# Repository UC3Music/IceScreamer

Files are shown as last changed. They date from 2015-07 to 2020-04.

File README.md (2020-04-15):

# IceScreamer
UC3Music's version of the well known green guitar pedal: Ibanez's Tube Screamer.

[Este mismo artículo en español](https://github.com/UC3Music/IceScreamer/blob/master/LEEME.md)

This project has a very similar electronics to Ibanez TS-808 TubeScreamer. Moreover this board let you choose among several modifications of the original design, and implement it easily. The most important modification is the ability to build a true bypass or buffered bypass pedal. Also there will be plenty of room for the most usual mods out there:

- Easier to provide "more gain"
- Easy to replace Op-Amp
- Easy to swap diodes (different distortion sounds)
- Easy to swap between flavors TS5, TS10 and TS808

## Choose from true bypass or pseudo true bypass.
From a manufacture perspective, true bypass isn't a convenient design, since it requires a big and expensive three pole, dual trow switch. And because it's bulkiness and complexity it needs to be soldered by hand. Buffered bypass is the way several manufacturers (Boss, Ibanez) reduced fabrication cost. However you need to solder 30 more components to get buffered bypass working, this circuit is more interesting in very automated manufacturing lines.

Among other benefits, true bypass means that, when your pedal is off, signal passes completely unaltered trough the pedal, as a wire tying together the input and output jack. Your tone will be perfect, however this bypass method has two disadvantages:

- A loud "click" sound can be made at the switch and then amplified by your guitar amp.
- If you are using long cable runs (i.e. 6m from guitar to pedalboard, then 6m from pedalboard to amp) you will have treble loss because guitar's high impedance output signal is affected a lot by cable capacitance.

Pseudo true bypass (buffered bypass) means that, when pedal is off, signal passes trough one or more buffers. A buffer is a kind of amplifier with gain of 1. Neither amplifies or attenuates signal. Buffers are designed to not alter the sound, but according to this [YouTube Video](https://www.youtube.com/watch?v=-oxBlWmeGE0), using more than five buffered pedals, bypass can trim down some bass frequencies and a little high frequencies. The benefits from buffered bypass are:

- No "click" silent switching.
- After the buffered pedal no matter how many cable meters you put, you no longer have treble loss. Pedal's output has low impedance, so cable capacitance reduce highs less.

TL;DR: using a lot of buffered bypass pedals is not good because you can end with a high-passed guitar sound. Using only true bypass pedals is not good if you handle long cable runs. Putting some buffered bypass pedal provide the best of the two worlds solution.

If you choose to build your IceScreamer with true bypass, short only "Short for TruBy" jumper located under "MILK" connector. If you choose to build your IceScreamer with pseudo true bypass, short only the two "Short both for Pseudo" jumpers, located in between input and output jacks.
Do it with a little of solder.

## Let's begin soldering
Components appears in the order it is meant to be soldered, from little to bigger size. If you need advice on how to solder, check this videos.
- [Tutorial SMT4Dummies by David Antón](https://www.youtube.com/watch?v=AYtE7eyIIUI&t=5s) Hand soldering wet technique.
- [Tutorial by informaticaIT](https://www.youtube.com/watch?v=BA7luKtNBzU) SMT with hot air gun.
- [Tutorial by ItsInOurKernel](https://www.youtube.com/watch?v=PU7wLcuqc-I) Hand soldering SMT.
- [Tutorial by EEVBlog](https://youtu.be/b9FC9fAlfQE?t=405) Hand soldering SMT.
- [Tutorial SMT4Dummies de JorFru (Spanish)](https://www.youtube.com/watch?v=6ee5rFPXXJo) Hand soldering dry technique.

## Where to place components?
Check the interactive component placement [viewer](http://music.uc3m.es/IceScreamer/BOM)

### Placing resistors
All resistors are SMD 2012(metric) or SMD 0805(imperial) size. You must have in mind all resistors measure 2,00mm x 1,25mm.
Resistors are thick film metal resistors.
10R stands for 10 ohms, 10K stands for 10000 ohms.

- R1, R2, R5, R6, R10, R15 and R17: 10K
- R3, R9, R11, R13: 1K
- R4, R14: 470K
- R7: 47K
- R8: 4,7K
- R12: 220R
- R16: 100R
- R18: SOLDER ONLY FOR TRUE BYPASS. Current limiting resistor for LED indicator. For using the ring LED provided in the BOM, use 470R. For single red LED on true bypass, use 680R.
- R19: 10K (only in case you are using a linear 100K potentiometer on volume and you want to provide a logarithmic feel)

If you are assembling true bypass, stop here. The following are the resistors for pseudo true bypass.

- R20 and R21: 470K
- R22, R26 and R32: 1M
- R23, R24, R30, R31, R34: 56K
- R25: 22K
- R27: 22R
- R28 and R29: 47K
- R33: 0R
- R35: current limiting resistor for pseudo true bypass LED indicator. 36K for standard red LED. Need calculation for other color.
- R36: 100R

### Capacitors
All capacitors are SMD 2012(metric), 0805(imperial) sized. To clarify: this component measures 2,0mm x 1,25mm.

Ceramic capsin case it is not specified.

- C3, C4, C12, C14, C15, C16, C17 and C18: 100nF
- C5: 22nF.
- C6 y C11: 1uF. Footprints are wrong here, you should solder polyester caps here, for improving the sound.
- C7: 47pF, Trough hole mounted
- C8: 47nF, Trough hole mounted
- C9: 220nF.
- C10: 220nF, Trough hole mounted
- C13: 10uF.

If you are assembling true bypass version, stop here. If you are assembling pseudo true bypass, continue soldering the following caps.
- C20: 100nF
- C21 and C27: 47nF
- C22, C25 and C26: 1nF
- C23 and C24: 100pF

### Diodes
Apart of D1 and D4 which are THD, others are 2012 metric (0805 imperial), however you can solder MicroMELF packages.

- D1: 1N4001, or any other general purpose 1A diode.
- D2 y D3: 1N4148
- D4: LED status (on/off) indicator

If you are assembling true bypass version, stop here. If you are assembling pseudo true bypass, continue soldering the following diodes.

- D20, D21 y D22: 1N4148
- D23: Zener 4.7V

### Transistors
Transistors are placed as seen on paintings on the board. If you are using other than the BC547, wich is suggested, pinouts will differ. Check this picture.
<p align="center">
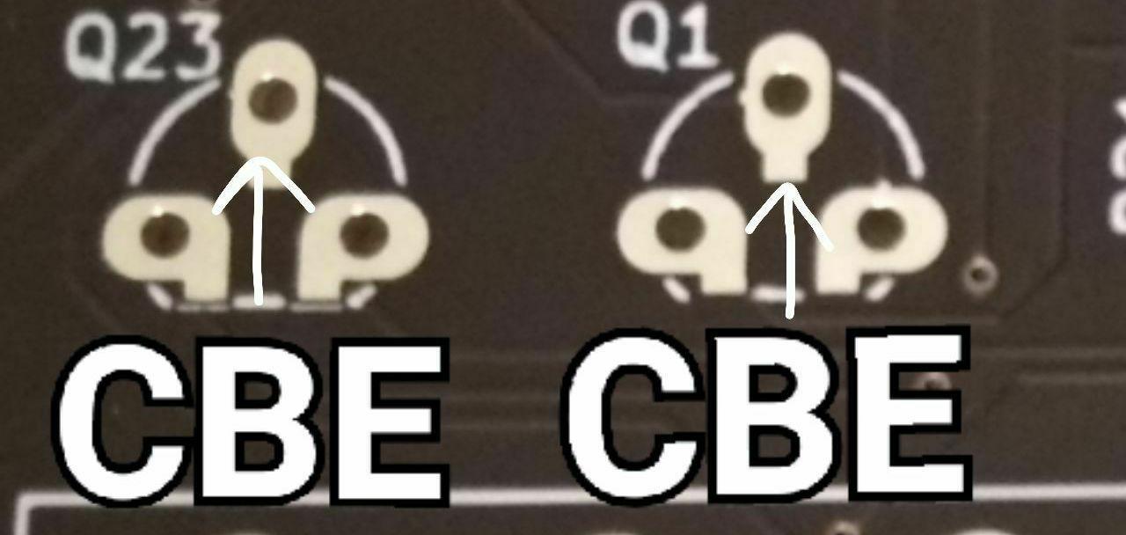
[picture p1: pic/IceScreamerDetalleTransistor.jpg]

</p>

- Q1, Q2: [BC547](https://www.tme.eu/es/details/bc547-cdi/transistores-npn-tht/cdil/bc547/). You can use any NPN transistor, but check pinouts.If you are assembling true bypass version, stop here. If you are assembling pseudo true bypass, continue soldering these transistors.

If you are assembling true bypass version, stop here. If you are assembling pseudo true bypass, continue soldering these transistors.

- Q20, Q21 y Q22: [BC547](https://www.tme.eu/es/details/bc547-cdi/transistores-npn-tht/cdil/bc547/). You can use any NPN transistor, but check pinouts.

- Q23 y Q24: [MMBF4392L](https://www.tme.eu/es/details/mmbf4392lt1g/transistores-con-canal-n-smd/on-semiconductor/). This is a JFET transistor. It's easy to find in CBE configuration.

### Integrated circuit
We recommend to install a socket for easy IC swapping.
U1: JRC4558. We use [RC4558](https://www.tme.eu/es/details/rc4558p/amplificadores-operativos-tht/texas-instruments/), but you can use any "dual OP-Amp", I.E.: NE5532,TL082, etc.

### Potentiometers
- ICE (Drive): 470K lineal
- CREAM (Tone): 20K lineal
- MILK (Level): 100K logarithmic or lineal installing 10K on R19. Learn more about Lin to Log conversion [here](https://learnabout-electronics.org/Resistors/resistors_09a.php)

### Switches
For True Bypass, solder a [3PDT](https://es.aliexpress.com/item/32530834644.html?spm=a2g0s.9042311.0.0.1ec663c0FUsGGv) (also called TPDT) switch in "SW_TruBy" mark.
If you are assembling pseudo true bypass, solder a momentary button [SPST](https://es.aliexpress.com/item/32918205335.html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,searchweb201602_,searchweb201603_) in the "SW_Pseudo" mark. Before soldering, put the cables trough the holes to secure it and avoid damage in case of strong pull.

### Battery cell
Battery cell Connect your battery lead to "9V Batt" mark, mind its polarity. Before soldering, put the cables through the holes to secure it and avoid damage in case of strong pull. Check picture.
<p align="center">
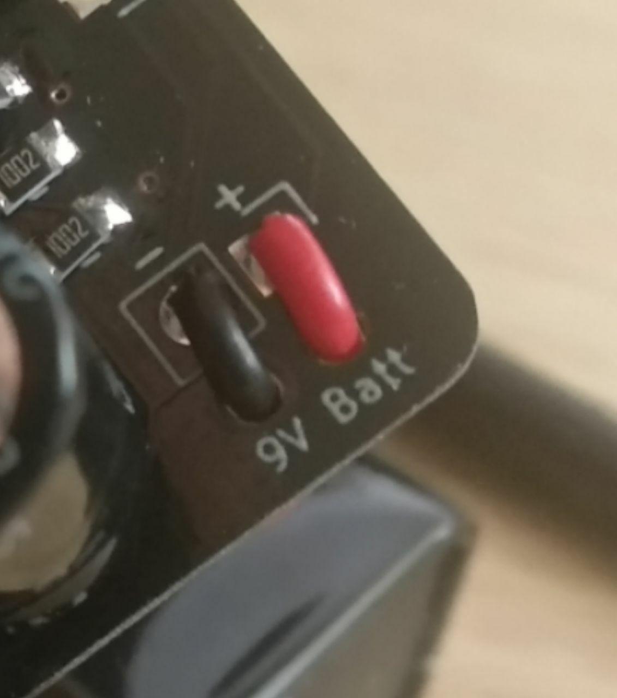
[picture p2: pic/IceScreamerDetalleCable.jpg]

</p>

### Big components last assembled

- C1 y C2: electrolytic caps, 220-470uF, at least 15V. Better use low-ESR. Lead spacing is 2.54mm.

### Jacks
Input and output are using Amphenol [ACJS-IH](https://www.tme.eu/en/details/acjs-ih/jack-connectors/amphenol/) connectors.
But seems that Neutrik [NMJ6HFD2](https://www.tme.eu/es/details/ntr-nmj6hfd2/conectores-jack/neutrik/nmj6hfd2/) are compatible too, not tested yet.

## Main mods
### More gain
If you want more distortion, lower that 4.7K R8 to get more gain when the drive control is maxed out. If you don't also want to change the bass/treble response, you will need to change the capacitor C8 as well. If you half the resistor, double the capacitor to keep the same overall frequency response. In example, R8 from 4.7K to 2.2K (you can use two 4.7K in parallel), C8 cap from 47nF to 100nF (you can use two 47nF caps in parallel)

It's also possible to increase gain potentiometer's value from 470K to 1M. 

### More bass
Increase C8 value. I.E.: C8 from 47nF to 100nF. Or 200nF if you already done the "more gain" mod.

### Swapping distortion flavour.
The stock units use a pair of silicon signal diodes, which are a 1N4148. If you change one of these diodes, chances are that the resulting pair will not clip at the same voltage for positive and negative signals, giving you asymmetrical clipping, and the resulting even order distortion. If you pick something close, like maybe a silicon power diode like the 1N400x series for the second diode, the resulting second harmonic will be very subtle, not audible as an octave effect at all, just a "sweeter" or more liquid tone.

You can try a number of things like putting one germanium (1N34A from Radio Shack works) diode in series with one of the silicons to add a bit more threshold voltage to one side. A more radical treatment would be the replacement of one of the silicons with three germaniums; even more radical would replace one of the silicons with TWO silicons. These last will start to make an octave effect just barely audible at some notes on the guitar neck.

I've even heard of using LED's in there for the clipping diodes. Go wild here.

## Otros mods:
On [this site](https://www.electrosmash.com/tube-screamer-analysis) I read that [this transistors](https://www.tme.eu/es/details/2sc1815-cen/transistores-npn-tht/central-semiconductor-corp/2sc1815/) are more silent than the suggested BC547. But check pin out when swapping transistors! However, on first prototypes, there's no noise issues with suggested parts. Through Q1 and Q2 is sound passing by, meanwhile there's no signal passing through Q20, Q21 nor Q22. If you are interesting in transistor swapping, consider only doing it on Q1 and Q2.

## References
This project and documentation were inspired in the following posts:
- http://www.geofex.com/Article_Folders/TStech/tsxfram.htm
- https://www.electrosmash.com/tube-screamer-analysis
- https://www.muzique.com/tech/scream.htm

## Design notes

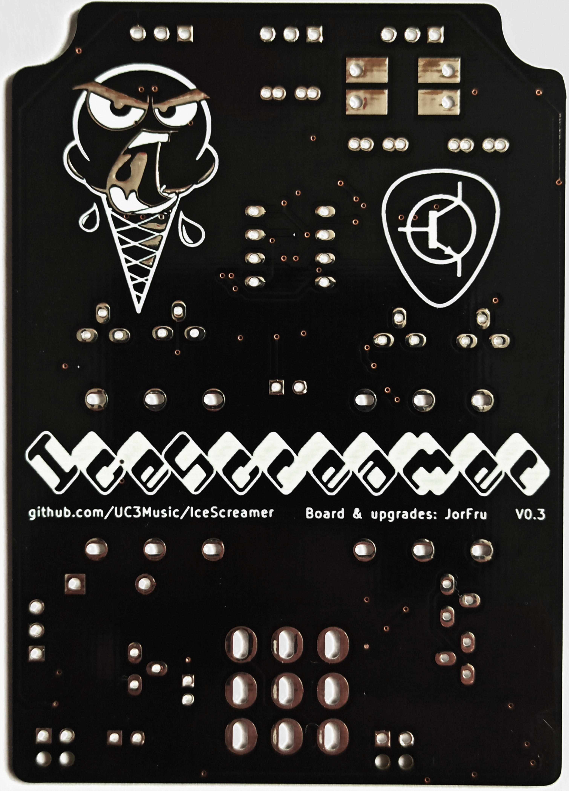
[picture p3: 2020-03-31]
pic/IceScreamerBottom.jpg

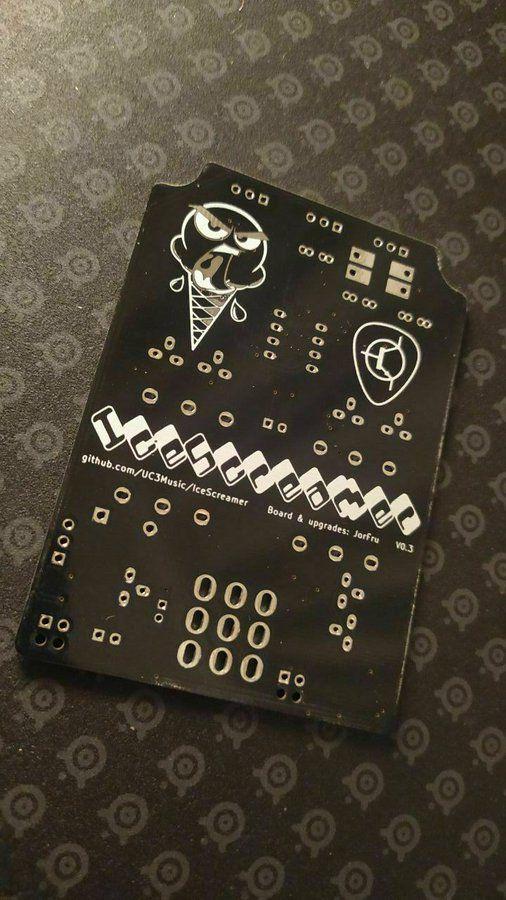
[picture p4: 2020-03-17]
pic/IceScreamerPic0.jpg

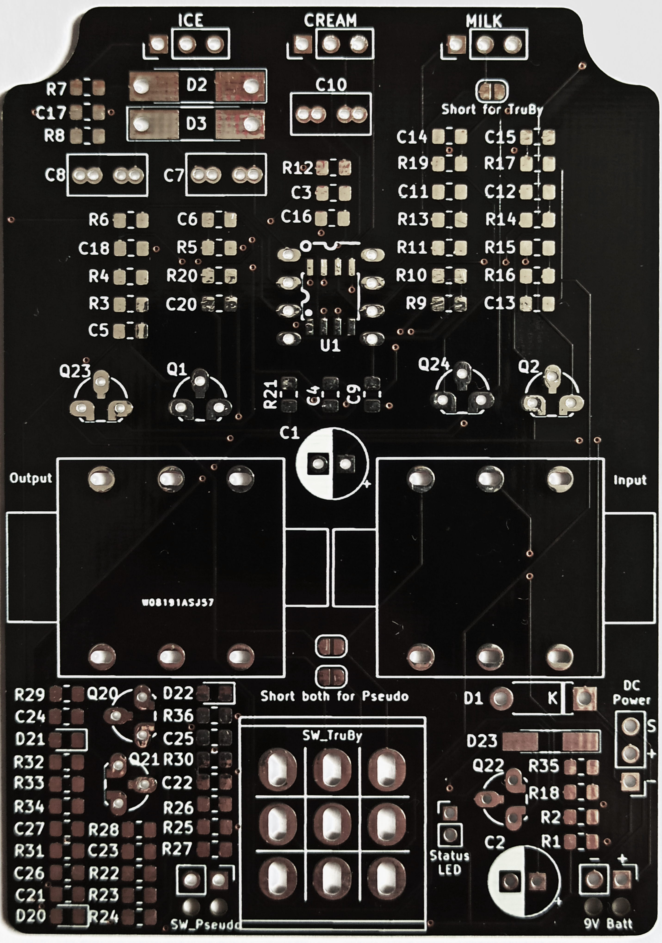
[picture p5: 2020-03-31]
pic/IceScreamerTop.jpg

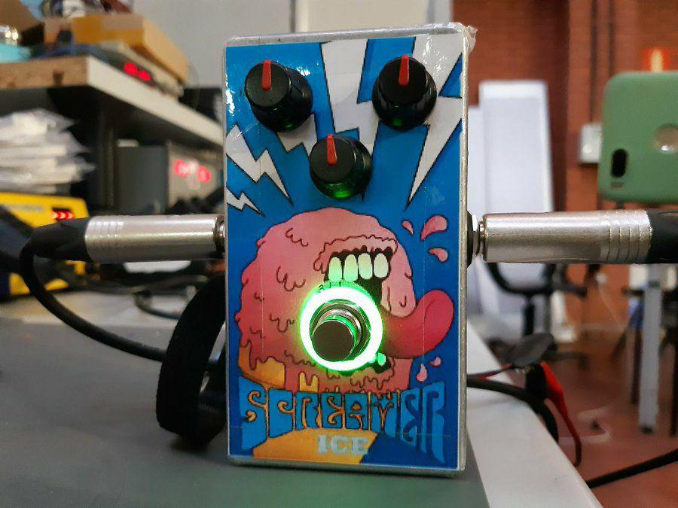
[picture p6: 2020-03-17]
pic/IceScreamerPic3.jpg

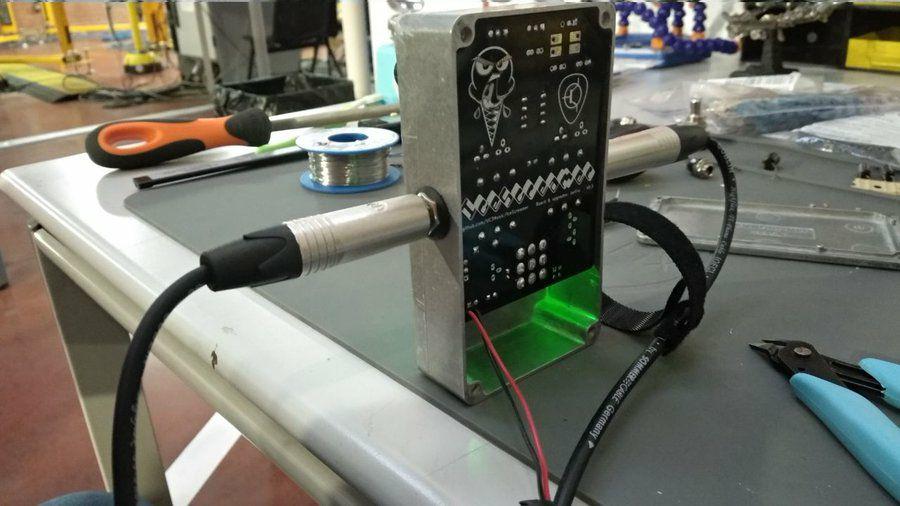
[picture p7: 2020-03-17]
pic/IceScreamerPic2.jpg

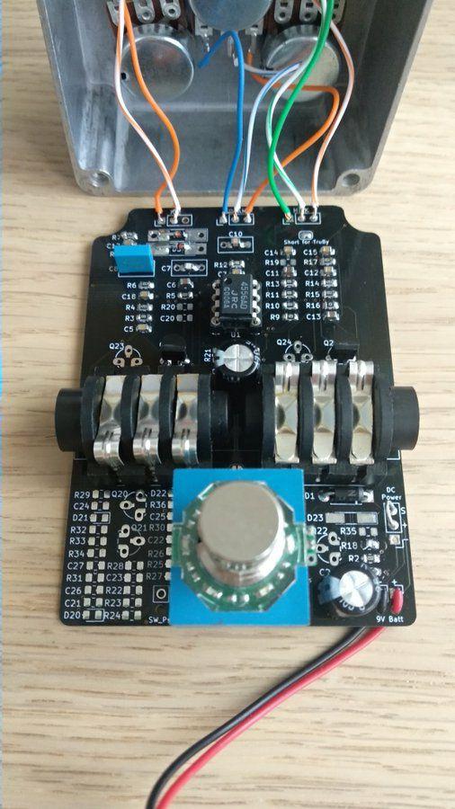
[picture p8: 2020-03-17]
pic/IceScreamerPic1.jpg

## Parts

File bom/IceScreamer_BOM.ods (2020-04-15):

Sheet: TrueByPass
Qty | Item | Manufacturer | Part Nº | Link | Supplier | Notes | Unit cost | Cost
1 | IC | TI | RC4558 | http://www.tme.eu/en/details/rc4558p/tht-operational-amplifiers/texas-instruments/ | TME | Actual part, ubiquitous | 0,15 | 0,15
1 | DIP socket |  | 1-2199298-2 | https://www.tme.eu/en/details/1-2199298-2/standard-dip-sockets/te-connectivity/ | TME |  | 0,21 | 0,21
1 | Enclosure | Hammond | 1550B | http://www.tme.eu/es/details/hm-1550b/carcasas-universales/hammond/1550b/ | TME |  | 5,75 | 5,75
2 | Jacks | Amphenol | acjx-ih | http://www.tme.eu/en/details/acjs-ih/jack-connectors/amphenol/ | TME |  | 0,83 | 1,66
0 | Alt Jack | Neutrik | NMJ6HCD2 |  |  |  | 0,00 | 0,00
1 | PCB | PCBWay, 123PCB, SeeedStudio, etc |  | https://www.pcbway.com/ | PCBWay |  | 1,40 | 1,40
1 | Pot TONE | SR PASSIVES | R16148-1A-2-B22K | http://www.tme.eu/en/details/r16148-1a-2-b22k/carbon-single-turn-axial-potentiometers/sr-passives/ | TME |  | 0,31 | 0,31
1 | Pot LEVEL | SR PASSIVES | R16148-1A-2-A100K | http://www.tme.eu/en/details/r16148-1a-2-a100k/carbon-single-turn-axial-potentiometers/sr-passives/ | TME |  | 0,31 | 0,31
1 | Pot GAIN | SR PASSIVES | R16148-1A-2-A500K | http://www.tme.eu/en/details/r16148-1a-2-a500k/carbon-single-turn-axial-potentiometers/sr-passives/ | TME |  | 0,31 | 0,31
3 | Knobs | SR PASSIVES | GMN-4GY | http://www.tme.eu/en/details/gmn-4gy/shaft-resistors-knobs/ | TME |  | 0,19 | 0,57
0 | Alt Knob | SR PASSIVES | GMN-4YL |  | TME |  |  | 0,00
0 | Alt Knob | SR PASSIVES | GMN-4RD |  | TME |  |  | 0,00
0 | Alt aluminium knob | SR PASSIVES |  | http://www.tme.eu/es/details/gs6m-15x16/perillas-para-potenciometros-de-eje/sr-passives/ | TME |  |  | 3,95
1 | Switch | Not sure |  | https://es.aliexpress.com/item/32785461116.html?spm=a2g0s.9042311.0.0.274263c0mmK5tz | AliExpress | Only for True Bypass | 3 | 3,00
0 | Alt switch | Electo-Harmonix |  | http://sonitube.es/footswitch-3pdt/ | Sonitube | Only for True Bypass | 3,95 | 0,00
1 | Momentary push foot button | Not sure |  | https://es.aliexpress.com/item/32787911852.html?spm=a2g0s.9042311.0.0.274263c0ryAaIM | AliExpress | Only for Pseudo True Bypass | 1,12 | 1,12
0 | Alt momentary push | Not sure |  | http://www.musikding.de/1PST-momentary-footswitch | Musikding | Only for Pseudo True Bypass | 2,50 | 0,00
2 | JFET | ON SEMICONDUCTOR | MMBF4392LT1G |  |  | Only for Pseudo True Bypass | 0,23 | 0,46
5 | NPN Transistor |  |  |  |  |  | 0,07 | 0,35
5 | Signal Diode |  | 1N4148-0805 |  | TME |  | 0,07 | 0,35
0 | Alt Signal Diode |  | 1N914BWS |  | TME |  | 0,07 | 0,00
1 | Power Diode | YANGJIE TECHNOLOGY | 1N4001-YAN |  | TME |  | 0,07 | 0,07
1 | Zener Diode | VISHAY | BZM55C4V7 |  | TME | Only for Pseudo True Bypass | 0,07 | 0,07
 | The components below are very easy to find
10 | Capacitor | AVX | 08055C105KAT2A |  | TME |  | 0,02 | 0,20
10 | Capacitor | AVX | 08051C104KAT2A |  | TME |  | 0,02 | 0,20
10 | Capacitor | AVX | 08053F224K4T4A |  | TME |  | 0,02 | 0,20
10 | Capacitor | KEMET | C0805C470J1GACAUTO |  | TME |  | 0,02 | 0,20
10 | Capacitor | KEMET | C0805C473K1RACAUTO |  | TME |  | 0,02 | 0,20
10 | Capacitor | KEMET | C0805C224K5RACAUTO |  | TME |  | 0,02 | 0,20
10 | Capacitor | KEMET | C0805C106K8PAC |  | TME |  | 0,02 | 0,20
10 | Capacitor | AVX | 08053C102KAT2A |  | TME |  | 0,02 | 0,20
10 | Capacitor | KEMET | C0805C101J5GACAUTO |  | TME |  | 0,02 | 0,20
10 | Resistor | ROYAL OHM | CQ0805-10K-1% |  | TME |  | 0,02 | 0,20
10 | Resistor | ROYAL OHM | CQ0805-100R-5% |  | TME |  | 0,02 | 0,20
10 | Resistor | ROYAL OHM | CQ0805-56K-1% |  | TME |  | 0,02 | 0,20
10 | Capacitor | EPCOS | B32529C105K |  | TME |  | 0,02 | 0,20
10 | Capacitor | EPCOS | B32529C0473J000 |  | TME |  | 0,02 | 0,20
10 | Capacitor | EPCOS | B32529C0223J000 |  | TME |  | 0,02 | 0,20
10 | Resistor | ROYAL OHM | CQ0805-22R-1% |  | TME |  | 0,02 | 0,20
10 | Resistor | ROYAL OHM | CQ0805-22K-1% |  | TME |  | 0,02 | 0,20
10 | Resistor | ROYAL OHM | CQ0805-1M-1% |  | TME |  | 0,02 | 0,20
10 | Resistor | ROYAL OHM | CQ0805-220R-1% |  | TME |  | 0,02 | 0,20
10 | Capacitor | VISHAY | CRCW08054K75FKTABC |  | TME |  | 0,02 | 0,20
10 | Resistor | ROYAL OHM | CQ0805-47K-1% |  | TME |  | 0,02 | 0,20
10 | Resistor | ROYAL OHM | CQ0805-1K-1% |  | TME |  | 0,02 | 0,20
10 | Resistor | ROYAL OHM | CQ0805-470K-1% |  | TME |  | 0,02 | 0,20
 |  |  |  |  |  |  | TOTAL | 24,64

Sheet: Pseudo
Qty | Item | Manufacturer | Part Nº | Link | Supplier | Notes | Unit cost | Cost
1 | IC | TI | RC4558 | http://www.tme.eu/en/details/rc4558p/tht-operational-amplifiers/texas-instruments/ | TME | Actual part, ubiquitous | 0,15 | 0,15
1 | Enclosure | Hammond | 1550B | http://www.tme.eu/es/details/hm-1550b/carcasas-universales/hammond/1550b/ | TME |  | 5,75 | 5,75
2 | Jacks | Amphenol | acjx-ih | http://www.tme.eu/en/details/acjs-ih/jack-connectors/amphenol/ | TME |  | 0,83 | 1,66
1 | PCB | Seeed |  |  | Seeed |  | 1,4 | 1,4
1 | Pot tono | SR PASSIVES | R16148-1A-2-B22K | http://www.tme.eu/en/details/r16148-1a-2-b22k/carbon-single-turn-axial-potentiometers/sr-passives/ | TME |  | 0,31 | 0,31 | Total unitario | TOTAL (IVA inc.)
1 | Pot volumen | SR PASSIVES | R16148-1A-2-A100K | http://www.tme.eu/en/details/r16148-1a-2-a100k/carbon-single-turn-axial-potentiometers/sr-passives/ | TME |  | 0,31 | 0,31
1 | Pot gain | SR PASSIVES | R16148-1A-2-A500K | http://www.tme.eu/en/details/r16148-1a-2-a500k/carbon-single-turn-axial-potentiometers/sr-passives/ | TME |  | 0,31 | 0,31
1 | Electronics |  |  |  |  |  | 3,5 | 3,5 | 14,55 | 352,11
3 | Perillas | SR PASSIVES | GMN-4GY | http://www.tme.eu/en/details/gmn-4gy/shaft-resistors-knobs/ | TME |  | 0,19 | 0,57 |  |  | Opción aluminio | http://www.tme.eu/es/details/gs6m-15x16/perillas-para-potenciometros-de-eje/sr-passives/
1 | DCJacks |  |  |  |  |  | 0,3 | 0,3
1 | Cell Clip |  |  |  |  |  | 0,09 | 0,09
 |  |  |  |  |  |  |  | 0
 |  |  |  |  |  |  |  | 0
 |  |  |  |  |  |  |  | 0
 |  |  |  |  |  |  |  | 0
 |  |  |  |  |  |  |  | 0
 |  |  |  |  |  |  |  | 0
 |  |  |  |  |  |  |  | 0
 |  |  |  |  |  |  |  | 0
 |  |  |  |  |  |  |  | 0
 |  |  |  |  |  |  |  | 0
1 |  |  |  | http://www.tme.eu/en/details/ps-03b/push-button-switches/ |  |  | 0,2 | 0,2
 |  |  |  |  |  |  |  | 0
 |  |  |  |  |  |  |  | 0
 |  |  |  |  |  |  |  | 0
TOTAL |  |  |  |  |  |  |  | 14,55

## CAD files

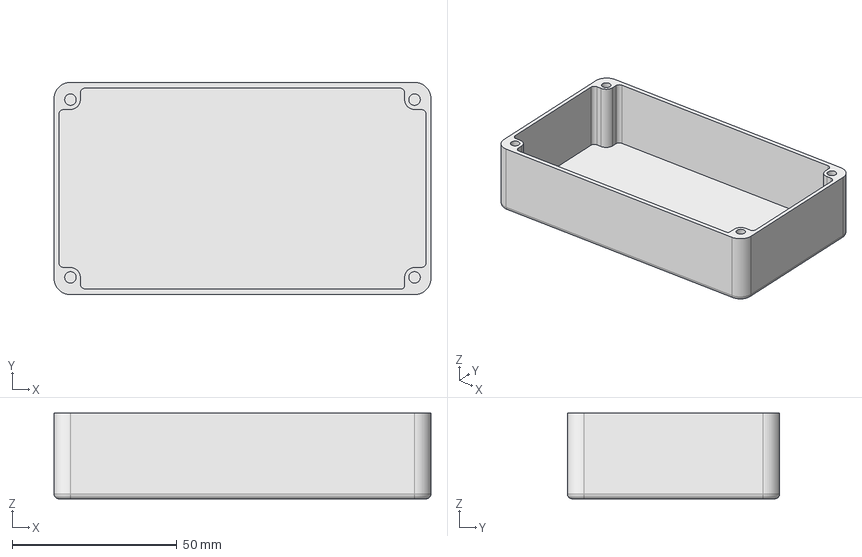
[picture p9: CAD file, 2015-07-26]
CAD/Hammond 1550B.fcstd
114.5 x 64.5 x 26.0 mm

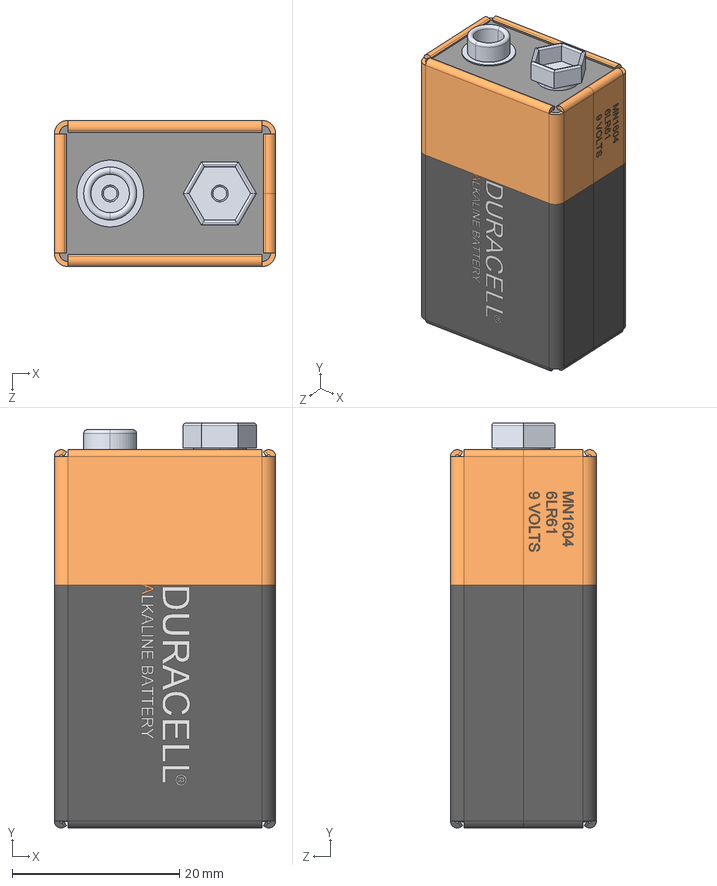
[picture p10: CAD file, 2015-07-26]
CAD/User Library-9V Duracell Battery-1.STEP
26.5 x 48.5 x 17.5 mm

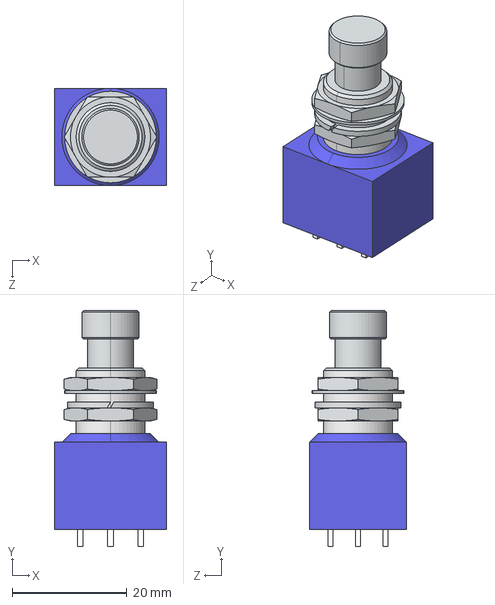
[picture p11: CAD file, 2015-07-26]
CAD/User Library-Footswich_3PDT.STEP
19.6 x 41.2 x 17.0 mm

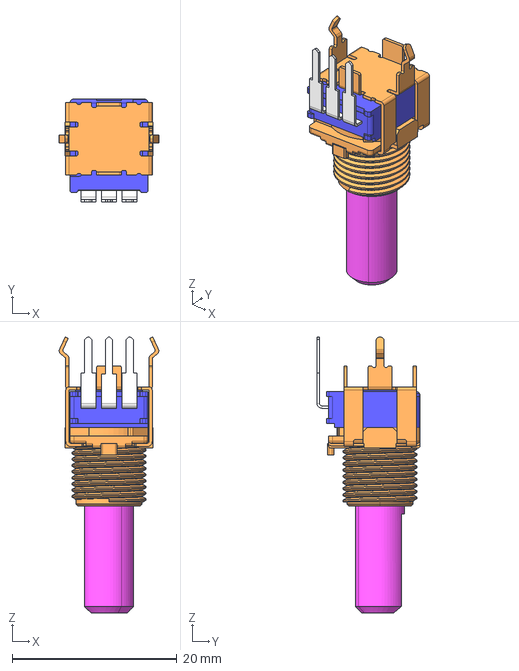
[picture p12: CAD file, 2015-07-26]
CAD/rk09l114001t.stp
12.1 x 12.5 x 33.5 mm

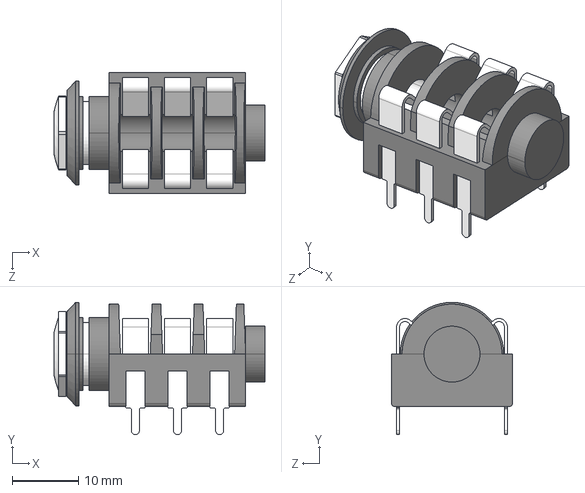
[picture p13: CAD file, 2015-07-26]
CAD/User Library-Audio Jack Neutrik Amphenol 6_35.STEP
31.8 x 19.9 x 18.2 mm
User Library-Audio Jack Neutrik Amphenol 6.35_SW3dPS-NMJ6HCD2_Imported5
User Library-Audio Jack Neutrik Amphenol 6.35_SW3dPS-NMJ6HCD2_Imported4

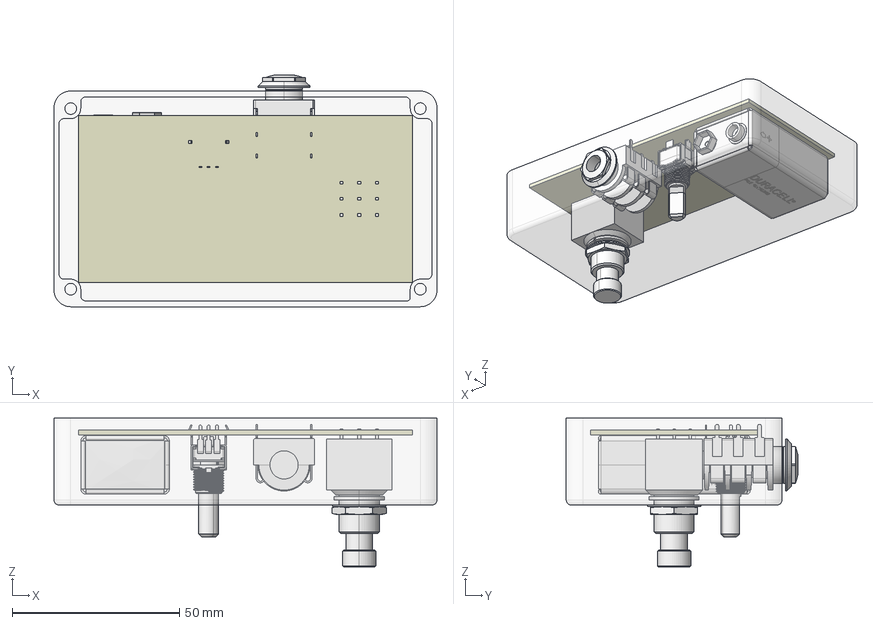
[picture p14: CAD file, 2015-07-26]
CAD/Pedal.fcstd
114.5 x 69.2 x 44.5 mm
User Library-Audio Jack Neutrik Amphenol 6.35
User Library-Audio Jack Neutrik Amphenol 6.036
User Library-Footswich_3PDT
User Library-Footswich_3PDT001
User Library-Footswich_3PDT002
User Library-Footswich_3PDT003
User Library-Footswich_3PDT004
User Library-Footswich_3PDT005
User Library-Footswich_3PDT006
User Library-Footswich_3PDT007
User Library-Footswich_3PDT008
User Library-Footswich_3PDT009
User Library-Footswich_3PDT010
User Library-Footswich_3PDT011
User Library-Footswich_3PDT012
User Library-Footswich_3PDT014
User Library-9V Duracell Battery-1
User Library-9V Duracell Battery-002
User Library-9V Duracell Battery-003
User Library-9V Duracell Battery-004

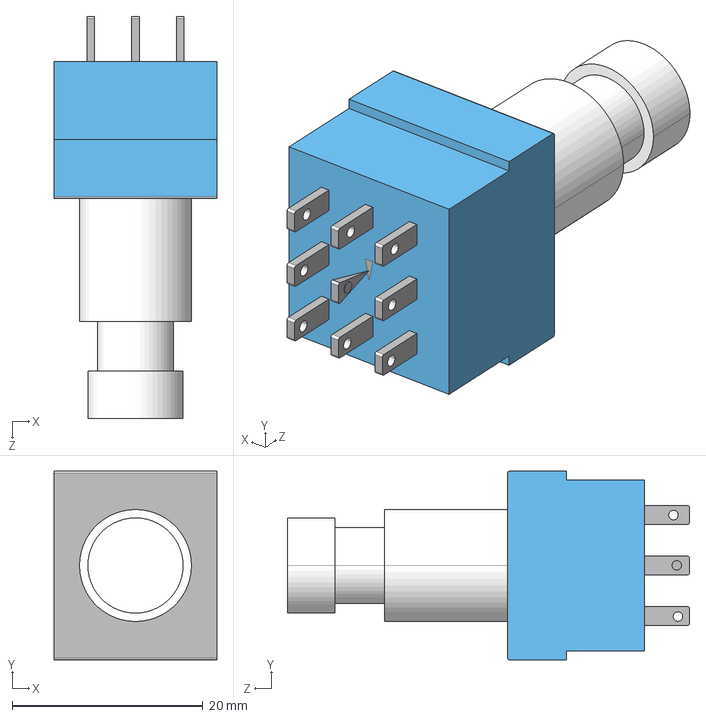
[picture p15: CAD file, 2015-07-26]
CAD/User Library-3P3T SWITCH.STEP
17.1 x 19.8 x 42.2 mm

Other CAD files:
CAD/box.step
CAD(legacy)/box.step

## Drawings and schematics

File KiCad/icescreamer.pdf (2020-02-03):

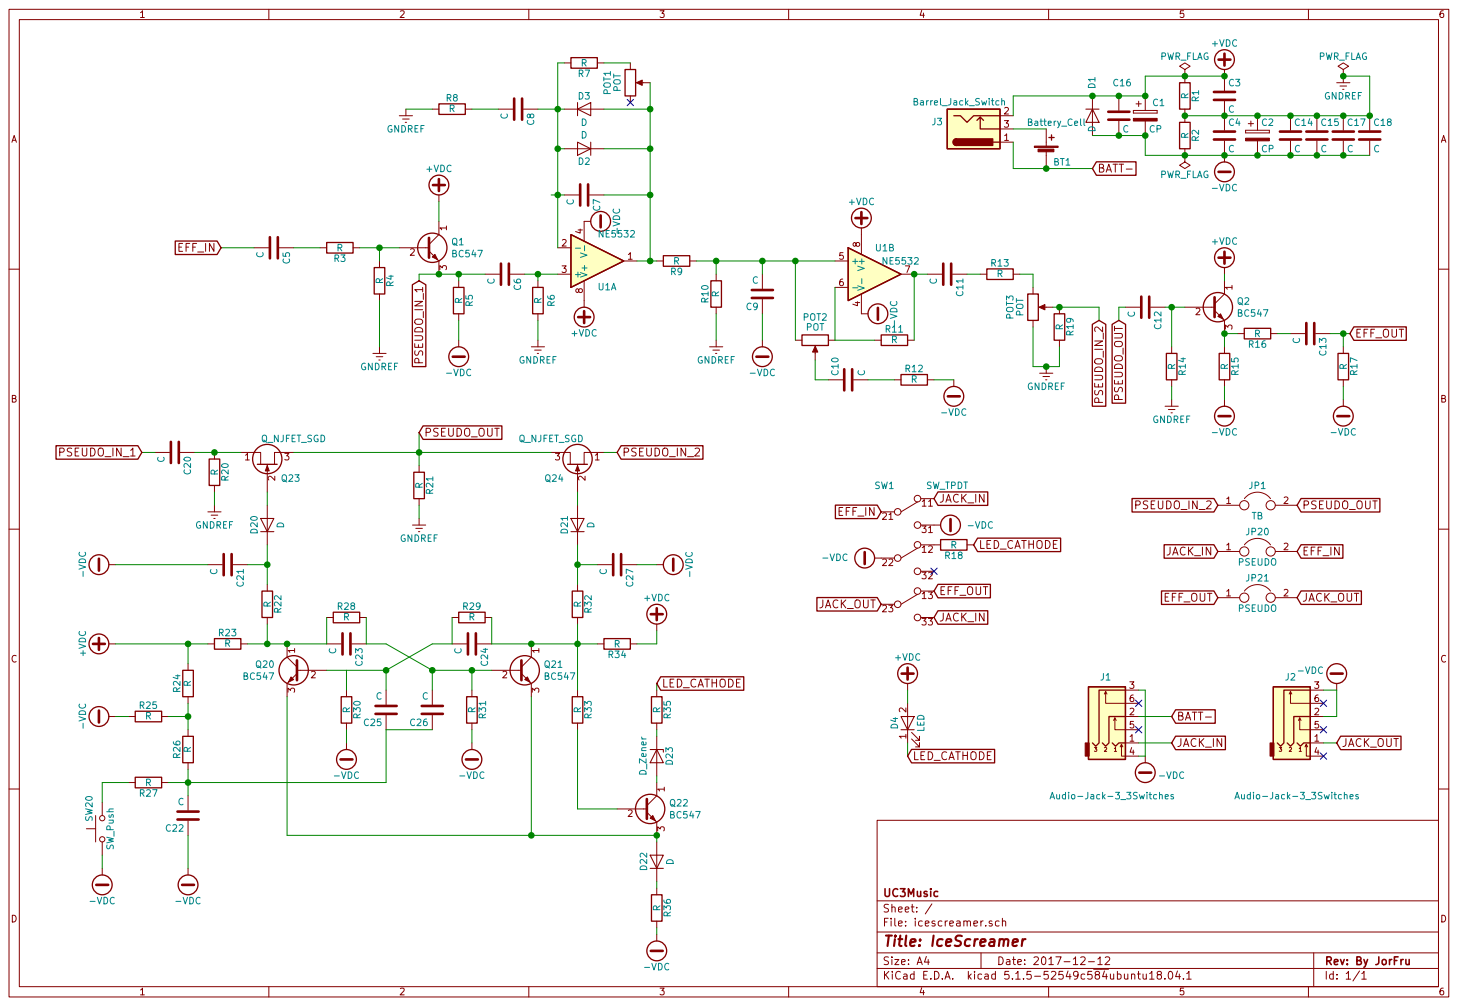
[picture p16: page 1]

Id: 1/1 Title: IceScreamer File: icescreamer.sch Sheet: / UC3Music

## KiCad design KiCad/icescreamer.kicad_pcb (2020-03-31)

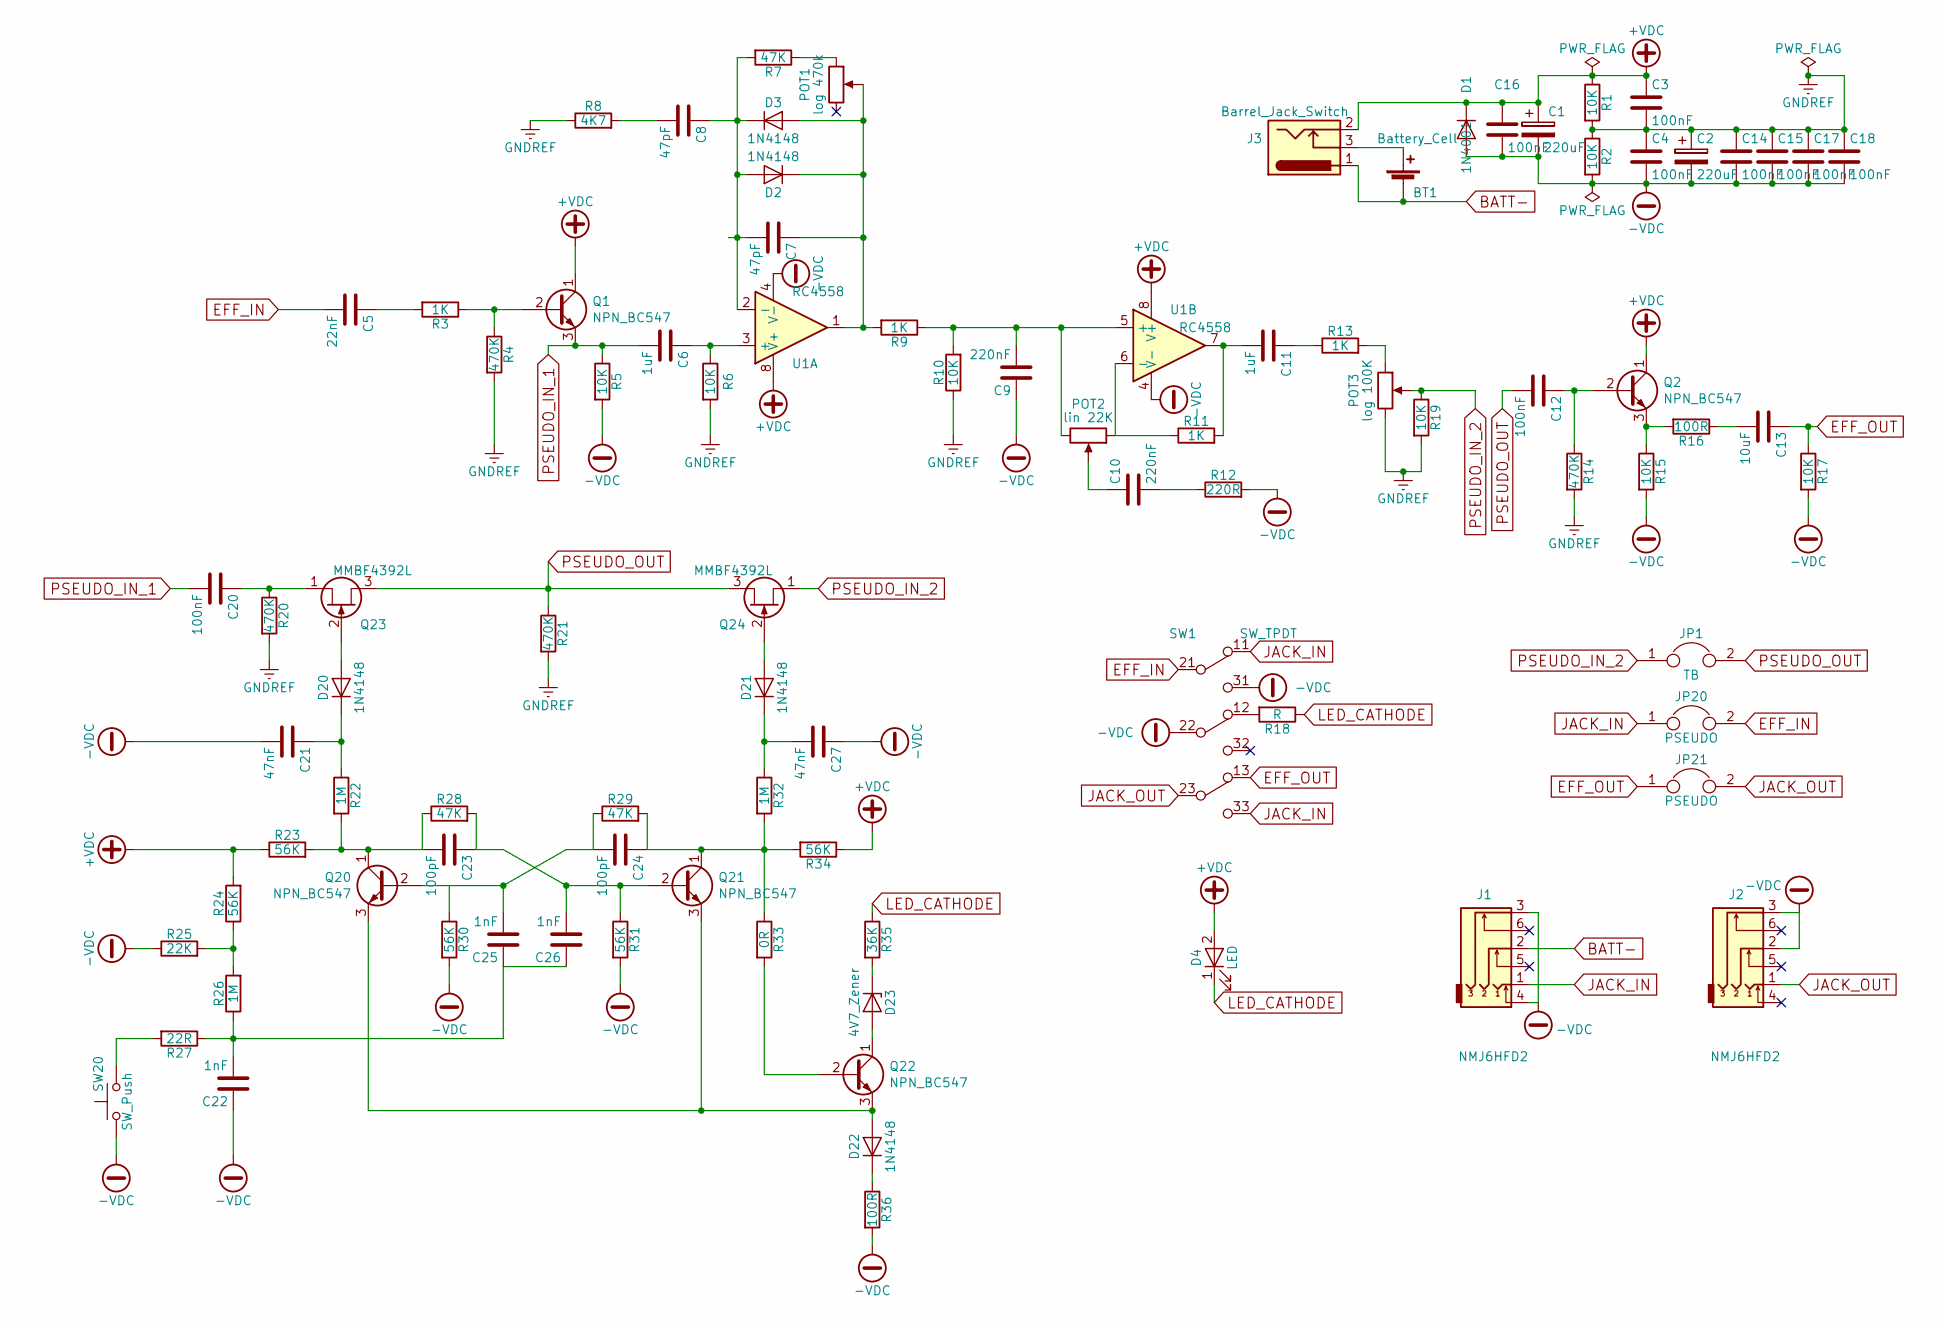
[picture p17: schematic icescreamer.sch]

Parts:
BT1: Battery_Cell; 1x02_P2.54mm_Hole
C1, C2: 220uF; CP_Radial_D6.3mm_P2.50mm
C3, C4, C12, C14, C15, C16, C17, C18, C20: 100nF; C_0805_2012Metric_Pad1.15x1.40mm_HandSolder
C5: 22nF; C_0805_2012Metric_Pad1.15x1.40mm_HandSolder
C6, C11: 1uF; C_0805_2012Metric_Pad1.15x1.40mm_HandSolder
C7, C8: 47pF; C_Rect_L7.0mm_W3.5mm_P2.50mm_P5.00mm
C9: 220nF; C_0805_2012Metric_Pad1.15x1.40mm_HandSolder
C10: 220nF; C_Rect_L7.0mm_W3.5mm_P2.50mm_P5.00mm
C13: 10uF; C_0805_2012Metric_Pad1.15x1.40mm_HandSolder
C21, C27: 47nF; C_0805_2012Metric_Pad1.15x1.40mm_HandSolder
C22, C25, C26: 1nF; C_0805_2012Metric_Pad1.15x1.40mm_HandSolder
C23, C24: 100pF; C_0805_2012Metric_Pad1.15x1.40mm_HandSolder
D1: 1N4001; D_DO-41_SOD81_P7.62mm_Horizontal
D2, D3: 1N4148; D_MELF-RM10_Universal_Handsoldering
D4: LED; PinHeader_1x02_P2.00mm_Vertical
D20, D21, D22: 1N4148; D_0805_2012Metric_Pad1.15x1.40mm_HandSolder
D23: 4V7_Zener; D_MiniMELF_Handsoldering
J1, J2: NMJ6HFD2; IceJACK
J3: Barrel_Jack_Switch; PinHeader_1x03_P2.54mm_Vertical
JP1: TB; SolderJumper-2_P1.3mm_Open_RoundedPad1.0x1.5mm
JP20, JP21: PSEUDO; SolderJumper-2_P1.3mm_Open_RoundedPad1.0x1.5mm
POT1: log 470k; PinHeader_1x03_P2.54mm_Vertical
POT2: lin 22K; PinHeader_1x03_P2.54mm_Vertical
POT3: log 100K; PinHeader_1x03_P2.54mm_Vertical
Q1, Q2, Q20, Q21, Q22: NPN_BC547; TO-92_SOT23_JorFru_compact
Q23, Q24: MMBF4392L; TO-92_SOT23_JorFru_compact
R1, R2, R5, R6, R10, R15, R17, R19: 10K; R_0805_2012Metric_Pad1.15x1.40mm_HandSolder
R3, R9, R11, R13: 1K; R_0805_2012Metric_Pad1.15x1.40mm_HandSolder
R4, R14, R20, R21: 470K; R_0805_2012Metric_Pad1.15x1.40mm_HandSolder
R7, R28, R29: 47K; R_0805_2012Metric_Pad1.15x1.40mm_HandSolder
R8: 4K7; R_0805_2012Metric_Pad1.15x1.40mm_HandSolder
R12: 220R; R_0805_2012Metric_Pad1.15x1.40mm_HandSolder
R16, R36: 100R; R_0805_2012Metric_Pad1.15x1.40mm_HandSolder
R18: R; R_0805_2012Metric_Pad1.15x1.40mm_HandSolder
R22, R26, R32: 1M; R_0805_2012Metric_Pad1.15x1.40mm_HandSolder
R23, R24, R30, R31, R34: 56K; R_0805_2012Metric_Pad1.15x1.40mm_HandSolder
R25: 22K; R_0805_2012Metric_Pad1.15x1.40mm_HandSolder
R27: 22R; R_0805_2012Metric_Pad1.15x1.40mm_HandSolder
R33: 0R; R_0805_2012Metric_Pad1.15x1.40mm_HandSolder
R35: 36K; R_0805_2012Metric_Pad1.15x1.40mm_HandSolder
SW1: SW_TPDT; IceStomp_Switch_3PDT
SW20: SW_Push; 1x02_P2.54mm_Hole
U1: RC4558; DIP8+SOIC8_2

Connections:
+VDC: C1.1, C3.1, C16.1, D1.1 (K), D4.2 (A), J3.2, Q1.1 (C), Q2.1 (C), R1.1, R23.1, R24.2, R34.1, U1.8 (V+)
-VDC: C1.2, C2.2, C4.2, C9.1, C14.2, C15.2, C16.2, C17.2, C18.2, C21.2, C22.1, C27.1, D1.2 (A), J1.3, J1.4, J2.2, J2.3, R2.2, R5.2, R12.2, R15.2, R17.2, R25.1, R30.2, R31.2, R36.2, SW1.22, SW1.31, SW20.1, U1.4 (V-)
BATT-: BT1.2 (-), J1.2, J3.1
EFF_IN: C5.2, JP20.2, SW1.21
EFF_OUT: C13.1, JP21.1, R17.1, SW1.13
GNDREF: C2.1, C3.2, C4.1, C14.1, C15.1, C17.1, C18.1, POT3.3, R1.2, R2.1, R4.2, R6.2, R8.1, R10.1, R14.2, R19.2, R20.2, R21.2
JACK_IN: J1.1, JP20.1, SW1.11, SW1.33
JACK_OUT: J2.1, JP21.2, SW1.23
LED_CATHODE: D4.1 (K), R18.1, R35.1
unnamed: BT1.1 (+), J3.3
unnamed: C5.1, R3.2
unnamed: C6.1, R6.1, U1.3 (+)
unnamed: C7.1, D2.1 (K), D3.2 (A), POT1.2, R9.2, U1.1
unnamed: C7.2, C8.1, D2.2 (A), D3.1 (K), R7.2, U1.2 (-)
unnamed: C8.2, R8.2
unnamed: C9.2, POT2.3, R9.1, R10.2, U1.5 (+)
unnamed: C10.1, POT2.2
unnamed: C10.2, R12.1
unnamed: C11.1, R13.1
unnamed: C11.2, R11.2, U1.7
unnamed: C12.1, Q2.2 (B), R14.1
unnamed: C13.2, R16.1
unnamed: C20.1, Q23.1 (S), R20.1
unnamed: C21.1, D20.1 (K), R22.1
unnamed: C22.2, C25.1, C26.1, R26.1, R27.1
unnamed: C23.1, C26.2, Q21.2 (B), R28.2, R31.1
unnamed: C23.2, Q20.1 (C), R22.2, R23.2, R28.1
unnamed: C24.1, Q21.1 (C), R29.2, R32.2, R33.1, R34.2
unnamed: C24.2, C25.2, Q20.2 (B), R29.1, R30.1
unnamed: C27.2, D21.1 (K), R32.1
unnamed: D20.2 (A), Q23.2 (G)
unnamed: D21.2 (A), Q24.2 (G)
unnamed: D22.1 (K), R36.1
unnamed: D22.2 (A), Q20.3 (E), Q21.3 (E), Q22.3 (E)
unnamed: D23.1 (K), R35.2
unnamed: D23.2 (A), Q22.1 (C)
unnamed: POT1.1, R7.1
unnamed: POT2.1, R11.1, U1.6 (-)
unnamed: POT3.1, R13.2
unnamed: Q1.2 (B), R3.1, R4.1
unnamed: Q2.3 (E), R15.1, R16.2
unnamed: Q22.2 (B), R33.2
unnamed: R18.2, SW1.12
unnamed: R24.1, R25.2, R26.2
unnamed: R27.2, SW20.2
PSEUDO_IN_1: C6.2, C20.2, Q1.3 (E), R5.1
PSEUDO_IN_2: JP1.1, POT3.2, Q24.1 (S), R19.1
PSEUDO_OUT: C12.2, JP1.2, Q23.3 (D), Q24.3 (D), R21.1

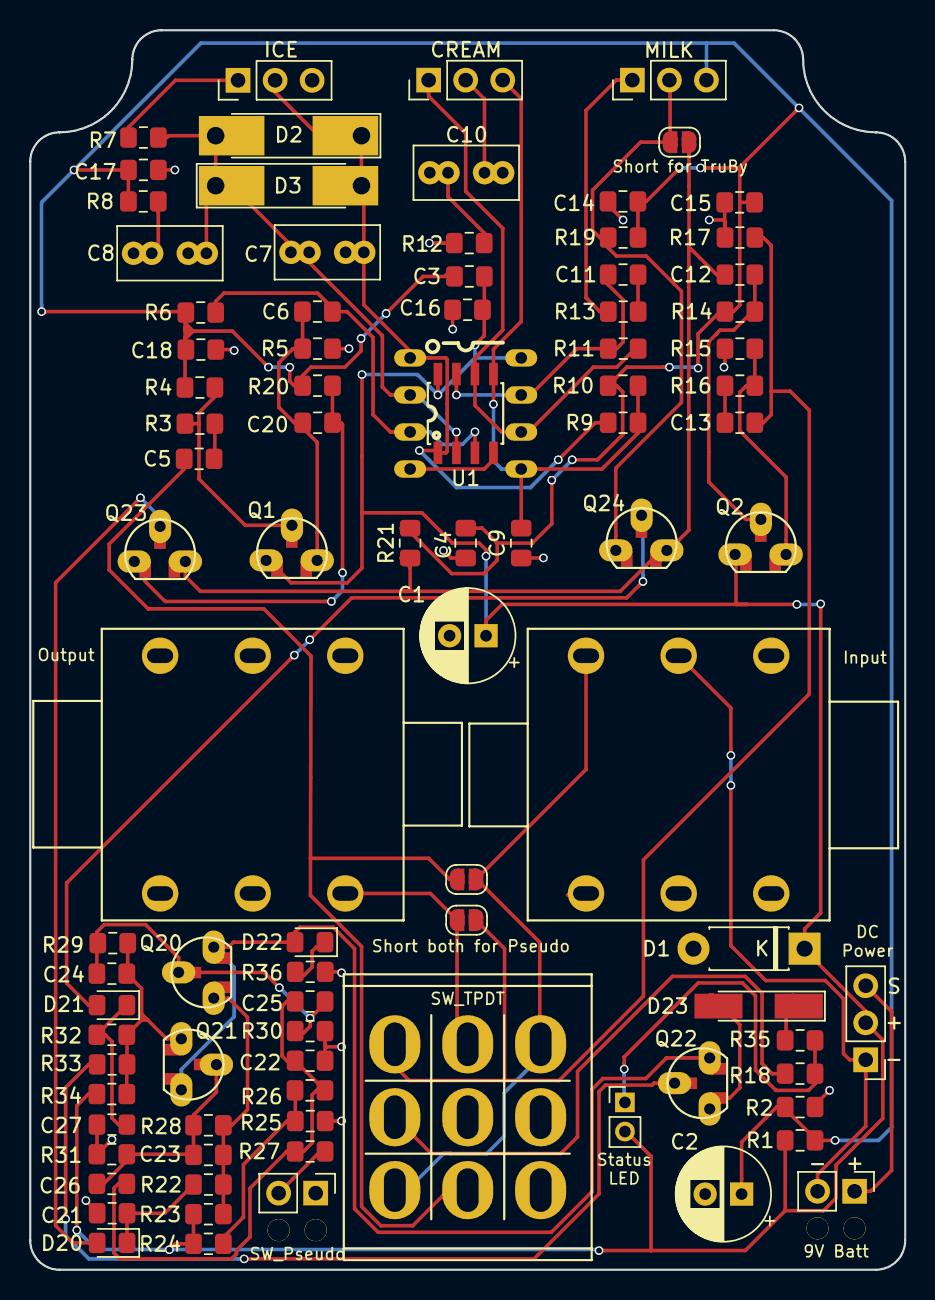
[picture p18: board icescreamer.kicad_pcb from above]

Board: 2 copper layers, 60.0 x 85.0 mm, 90 parts (0 on the bottom side), 48 nets.

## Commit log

2015-03-24 Added kicad-library as submodule
2015-03-24 Add schematic files
    [tubescreamer.sch]
2015-03-24 Add some values
    [tubescreamer.sch]
2015-03-30 colocados los valores de los componentes
    [tubescreamer.sch]
2015-03-30 renamed files
    [icescreamer.sch]
2015-03-30 schematic almost finished
    [icescreamer.sch]
2015-03-31 after some night-working!
    [icescreamer.sch]
2015-04-05 Correct issues in schematic, add pcb file
    [icescreamer.kicad_pcb, icescreamer.sch]
2015-04-05 Add outline
    [icescreamer.kicad_pcb]
2015-04-05 Add components to pcb file, add temp component to this main repo as backup
    [icescreamer.kicad_pcb]
2015-04-06 Add comment about recommended transistors
    [icescreamer.sch]
2015-04-07 Add resistor to convert volume pot from linear to log
    [icescreamer.sch]
2015-04-07 Updated kicad-lib with female jack symbol
2015-04-07 Update jack symbol in schematic
    [icescreamer.sch]
2015-04-07 Update footprint for female jack in netlist
    [icescreamer.kicad_pcb, icescreamer.sch]
2015-04-12 added pot footprint
2015-04-12 borrado el antiguo
2015-04-18 Update female jack pinout
    [icescreamer.kicad_pcb]
2015-05-03 Add new footprints
    [icescreamer.kicad_pcb, icescreamer.sch]
2015-07-26 Add CAD files for pedal
    [Hammond 1550B.fcstd, Pedal.fcstd, User Library-3P3T SWITCH.STEP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]
2016-11-10 Added docs to doc folder and moved KiCad files to folder KiCad
    [Presupuesto IceScreamer.ods, icescreamer.kicad_pcb, icescreamer.sch]
2017-07-17 Added BOM
    [BOM.ods]
2017-07-18 Updated components on schematic with newer ones. EdgeCuts on board already has the proper size. Added custom potentiometer footprint.
    [icescreamer.sch]
2017-08-29 added IceJACK footprint and adjusted edge cuts
2017-08-29 new edge cuts. It should work
    [icescreamer.kicad_pcb]
2017-12-12 REDOed Schematic. Now supports both TrueBypass and PseudoBypass at the same time
    [icescreamer.kicad_pcb, icescreamer.sch]
2017-12-13 Asociadas las huellas a los componentes
    Falta trabajar sobre esto, cotejando los componentes que se compraron y comprobar que las huellas que se eligen sean adecuadas para soldar a mano.
    [icescreamer.sch]
2017-12-14 Updated asociación de huellas
    [icescreamer.sch]
2017-12-15 Lo mismo que antes pero un poco más afinado.
    [icescreamer.sch]
2017-12-17 Añadidos archivos de huellas
    DIP8+SOIC8 importado de Drawdio
    3PDT tomado de def-footprints
    [icescreamer.sch]
2017-12-20 Colocando componentes
    [icescreamer.kicad_pcb]
2017-12-21 Colocando componentes II
    [icescreamer.kicad_pcb]
2018-02-02 pseudo circuit laid out
    [icescreamer.kicad_pcb]
2020-01-30 JorFru approved
    [icescreamer.kicad_pcb, icescreamer.sch]
2020-02-02 V0.3 ready
    [icescreamer-B_Cu.gbr, icescreamer-B_Mask.gbr, icescreamer-B_SilkS.gbr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]
2020-02-03 V0.3 release
    [icescreamer-B_Cu.gbr, icescreamer-B_Mask.gbr, icescreamer-B_SilkS.gbr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]
2020-02-04 arreglado problema con el dibujo trasero
    [BOM.ods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]
2020-02-09 mandado a fabricar, ya no hay vuelta atrás
    [icescreamer-B_Cu.gbr, icescreamer-B_Mask.gbr, icescreamer-B_SilkS.gbr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]
2020-02-19 Añadido BOM condensadores
2020-02-19 Añadidas resistencias
2020-02-19 actualizada información de los condensadores
2020-03-29 añadido BOM interactivo
    [icescreamer.sch]
2020-03-31 update de la PCB con los valores de los componentes marcados
    [icescreamer.kicad_pcb]
2020-03-31 añadido BOM actualizado
    [IceScreamer_BOM.ods]
2020-03-31 fotos añadidas, docs borrados
    [BOM.ods, Presupuesto IceScreamer.ods]
2020-03-31 renombrada carpeta CAD, archivos antiguos que ya no se usan
    [Hammond 1550B.fcstd, Pedal.fcstd, User Library-3P3T SWITCH.STEP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]
2020-03-31 añadida la fuente de las letras
2020-04-04 Intentando ver bom como web
2020-04-15 archivos viejos archivados
    [IceScreamer_BOM.ods]
